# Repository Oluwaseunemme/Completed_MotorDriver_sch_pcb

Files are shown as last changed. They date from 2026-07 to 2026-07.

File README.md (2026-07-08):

# Completed_MotorDriver_sch_pcb
A few days ago, I shared the schematic for my custom 4-channel Arduino motor driver built around the 74HC595 shift register and L293D motor drivers. Today, I'm excited to share some progress—the design is now fully functional in simulation, and I've begun developing the software library that powers it.

🔹 From Hardware to Software

One of the goals of this project wasn't just to design the hardware, but to build a reusable and intuitive software interface for controlling it.

Instead of manually controlling each motor direction pin, the library uses bitwise operations to combine the direction of all four motors into a single 8-bit value. That byte is then transmitted to the 74HC595 using Arduino's shiftOut() function, updating all motor direction outputs simultaneously.

Each motor is represented using a simple 2-bit encoding:

• 10 → Forward
• 01 → Backward
• 00 → Stop

So, a binary value like:

10100110

contains the complete direction information for all four motors.

🔹 A Closer Look at the Logic

One part I particularly enjoyed implementing was the binary-to-byte conversion using bitwise operators.

value <<= 1;

if (strValue[i] == '1')
    value |= 1;

The left-shift operator (<<) moves the existing bits one position to the left, creating room for the next bit. The OR assignment operator (|=) then sets only the least significant bit when needed, without affecting the bits that have already been built.

It's a small piece of code, but it's a great reminder of how low-level bit manipulation directly translates into controlling real hardware.

🔹 Efficient GPIO Usage

By using the 74HC595 as a direction controller, the Arduino only needs three digital pins to control the direction of all four motors, regardless of how many outputs are driven by the shift register.

Meanwhile, each L293D enable pin is connected to a dedicated PWM pin, allowing independent speed control for every motor while keeping GPIO usage to a minimum.

This combination provides a clean separation between:

Direction control (Shift Register)
Speed control (PWM)
Power driving (L293D)

🔹 Current Progress

✅ 4 independent DC motor channels
✅ Individual PWM speed control
✅ Direction control through a single 74HC595 shift register
✅ Object-oriented Arduino driver library under development
✅ Successfully validated in Proteus simulation

🔹 What's Next?

The next phase is moving from simulation to a physical prototype, followed by refining the library to make it easier for anyone to integrate the driver into robotics and embedded projects.

Projects like this continue to remind me that embedded systems are where software and hardware truly meet. A few lines of C++ and some bitwise operations eventually become electrical signals that move real motors—and that's one of the most rewarding parts of embedded engineering.

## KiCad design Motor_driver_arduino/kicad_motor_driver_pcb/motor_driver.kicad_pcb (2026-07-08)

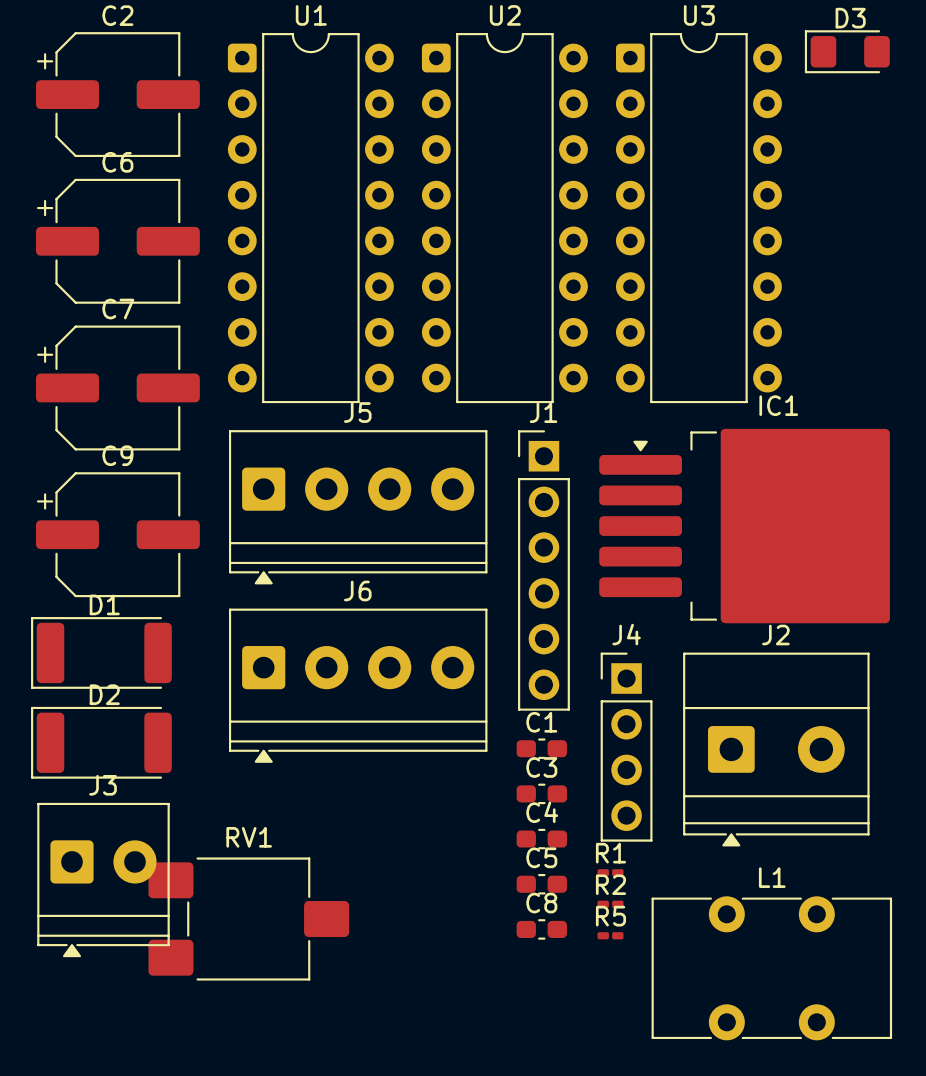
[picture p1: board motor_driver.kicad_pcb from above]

Board: 2 copper layers, 27 parts (0 on the bottom side), 35 nets, no tracks yet.

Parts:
C1, C3, C4, C5: 100nf; C_0603_1608Metric_Pad1.08x0.95mm_HandSolder
C2, C6, C7: 20uf; CP_Elec_6.3x5.4
C8: 0.15uf; C_0603_1608Metric_Pad1.08x0.95mm_HandSolder
C9: 2000uf; CP_Elec_6.3x5.4
D1, D2: LED; LED_2512_6332Metric_Pad1.52x3.35mm_HandSolder
D3: 1N5821; D_1206_3216Metric_Pad1.42x1.75mm_HandSolder
IC1: LM2577; TO-263-5_TabPin3
J1: Conn_01x06_Pin; PinHeader_1x06_P2.54mm_Vertical
J2: Motor/load supply; TerminalBlock_Phoenix_MKDS-1,5-2_1x02_P5.00mm_Horizontal
J3: chip supply +5v; TerminalBlock_Phoenix_PT-1,5-2-3.5-H_1x02_P3.50mm_Horizontal
J4: Conn_01x04_Pin; PinHeader_1x04_P2.54mm_Vertical
J5: M1/M2; TerminalBlock_Phoenix_PT-1,5-4-3.5-H_1x04_P3.50mm_Horizontal
J6: M3/M4; TerminalBlock_Phoenix_PT-1,5-4-3.5-H_1x04_P3.50mm_Horizontal
L1: L_Ferrite; L_CommonMode_Toroid_Vertical_L13.0mm_W7.5mm_Px6.00mm_Py5.00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
R1: 500; R_0201_0603Metric_Pad0.64x0.40mm_HandSolder
R2: 1k; R_0201_0603Metric_Pad0.64x0.40mm_HandSolder
R5: 2.2k; R_0201_0603Metric_Pad0.64x0.40mm_HandSolder
RV1: 10k; Potentiometer_ACP_CA6-VSMD_Vertical
U1, U3: L293D; DIP-16_W7.62mm
U2: 74HC595; DIP-16_W7.62mm

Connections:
GND: C2.2, C6.2, C7.2, C8.2, C9.2, D1.1 (K), D2.1 (K), IC1.3 (GND), J1.6, J2.2, J3.2, RV1.1, U1.4 (GND), U1.5 (GND), U1.12 (GND), U1.13 (GND), U2.8 (GND), U3.4 (GND), U3.5 (GND), U3.12 (GND), U3.13 (GND)
L1E1: J4.1, U1.1 (EN1,2)
L1E2: J4.2, U1.9 (EN3,4)
L2E1: J4.3, U3.1 (EN1,2)
L2E2: J4.4, U3.9 (EN3,4)
Lvcc: C6.1, J3.1, R1.1, U1.16 (VCC1), U2.16 (VCC), U3.16 (VCC1)
Mvc: C9.1, D3.1 (K), RV1.3, U1.8 (VCC2)
Mvcc: C2.1, C7.1, IC1.5 (VIN), J2.1, L1.1, R2.1, U3.8 (VCC2)
unnamed: C8.1, R5.2
unnamed: D1.2 (A), R2.2
unnamed: D2.2 (A), R1.2
unnamed: D3.2 (A), IC1.4 (VSW), L1.2
unnamed: IC1.1 (COMP), R5.1
unnamed: IC1.2 (FB), RV1.2
unnamed: J1.1, U2.14 (SER)
unnamed: J1.2, U2.11 (SRCLK)
unnamed: J1.3, U2.10 (~SRCLR)
unnamed: J1.4, U2.12 (RCLK)
unnamed: J1.5, U2.13 (~OE)
unnamed: C1.1, J5.1, U1.3 (1Y)
unnamed: C1.2, J5.2, U1.6 (2Y)
unnamed: C3.1, J5.3, U1.11 (3Y)
unnamed: C3.2, J5.4, U1.14 (4Y)
unnamed: C4.1, J6.1, U3.3 (1Y)
unnamed: C4.2, J6.2, U3.6 (2Y)
unnamed: C5.1, J6.3, U3.11 (3Y)
unnamed: C5.2, J6.4, U3.14 (4Y)
unnamed: U1.2 (1A), U2.15 (QA)
unnamed: U1.7 (2A), U2.1 (QB)
unnamed: U1.10 (3A), U2.2 (QC)
unnamed: U1.15 (4A), U2.3 (QD)
unnamed: U2.4 (QE), U3.2 (1A)
unnamed: U2.5 (QF), U3.7 (2A)
unnamed: U2.6 (QG), U3.10 (3A)
unnamed: U2.7 (QH), U3.15 (4A)

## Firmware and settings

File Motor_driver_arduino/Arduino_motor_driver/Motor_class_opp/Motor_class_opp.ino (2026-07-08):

const uint8_t L1E1= 3, L1E2= 5, L2E1= 6, L2E2= 8, LATCHPIN= 9, CLOCKPIN= 12, DATAPIN= 11;

class motorDriver{
  private:
    uint8_t _latch;
    uint8_t _clock;
    uint8_t _data;
    uint8_t _l1e1, _l1e2, _l2e1, _l2e2;

    void _pushData(byte datas){//helps push out data to the register
      digitalWrite(_latch, LOW);
      shiftOut(_data, _clock, LSBFIRST, datas);
      digitalWrite(_latch, HIGH);
    }

    String _setBin(const String& command){
      if (command == "forward")  return "10";
      else if (command == "backward") return "01";
      else if (command == "off")      return "00";
      else {
        Serial.println("Error input....please enter valid input!!!!!!");
      }
    }
    byte _stringToByte(const String& strValue) {
      byte value = 0;
      for (uint8_t i = 0; i < 8; i++) {
        value <<= 1;
        if (strValue[i] == '1') value |= 1;
      }
      return value;
}

  public:
    motorDriver(const uint8_t latchPin, const uint8_t clockPin, const uint8_t dataPin, const uint8_t l1e1Pin, const uint8_t l1e2Pin, const uint8_t l2e1Pin, const uint8_t l2e2Pin){
      _latch=latchPin;
      _clock=clockPin;
      _data=dataPin;
      _l1e1=l1e1Pin;
      _l1e2=l1e2Pin;
      _l2e1=l2e1Pin;
      _l2e2=l2e2Pin;
    }
    
    void init(){//helps innitializes shift registers pin for their respective mode
      pinMode(_latch, OUTPUT);
      pinMode(_data, OUTPUT);
      pinMode(_clock, OUTPUT);
      //below lines helps to initialize motor speed
      analogWrite(_l1e1, 140);
      analogWrite(_l1e2, 190);
      analogWrite(_l2e1, 250);
      analogWrite(_l2e2, 0);
    }

    
    void setSpeed(uint8_t motorName, const uint8_t speed){//helps set individua motor speed i.e 'M1' for motor 1 or 'M2' for motor 2"
      switch(motorName){
        case 1 :analogWrite(_l1e1, speed);
        break;
        case 2 :analogWrite(_l1e2, speed);
        break;
        case 3 :analogWrite(_l2e1, speed);
        break;
        case 4 :analogWrite(_l2e2, speed);
        break;
        default: Serial.println("Enter recognized motor name i.e '1' for motor 1 or '2' for motor 2.........");
      }
         Serial.println("Motor "+String(motorName)+" speed:"+String(speed));
    }

    void setDirection(const String& motor1State, const String& motor2State, const String& motor3State, const String& motor4State){//motor state can wither be 'forward', 'backward', 'off'
       String strByte = _setBin(motor1State)+_setBin(motor2State)+_setBin(motor3State)+_setBin(motor4State);
       byte data=  _stringToByte(strByte);
       Serial.println(data, BIN);
       _pushData(data);
    }

};

motorDriver myDriver = motorDriver(LATCHPIN, CLOCKPIN, DATAPIN, L1E1, L1E2, L2E1, L2E2);
void setup(){
  myDriver.init();
  Serial.begin(9600);
}
bool isChange=true;
long interval=1000, lastime;
void loop(){
    //int m1Speed = map(analogRead(A0), 0, 1023, 0, 255);
    if(millis()-lastime>=interval){lastime=millis();
      //Serial.println("m1 speed:"+String(analogRead(A0)));
       myDriver.setSpeed(1 , 200);
       myDriver.setSpeed(2 , 255);
      myDriver.setSpeed(3 , 255);
      myDriver.setSpeed(4 , 255);
      myDriver.setDirection("forward", "forward", "backward", "forward");
     }
}

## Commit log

2026-07-08 main files upload commit
    [motor_driver.kicad_pcb]
2026-07-15 Motor driver folder update
